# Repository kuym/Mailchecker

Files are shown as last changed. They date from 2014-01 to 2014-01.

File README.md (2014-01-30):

MailChecker2
============

This Electric Imp-powered device detects motion and reports it to you over the web.  It was originally designed to be stuck to a mailbox door
to notify you over WiFi when mail is delivered.  It could also be used to monitor doors (including garage or pet doors), valuables that you
don't want moved or cookie jars you want to keep children out of.

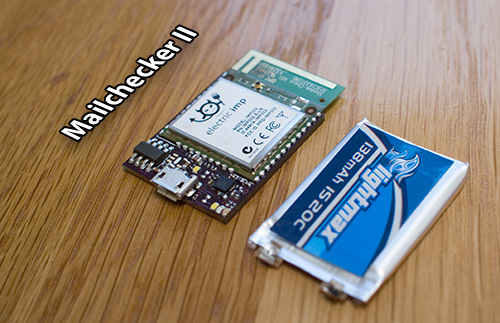
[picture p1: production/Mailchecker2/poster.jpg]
Poster


## Features

The board features an accelerometer, light sensor and Lithium-ion/polymer battery recharging built in.  It achieves approximately one month
of use between charges per 100mAh of battery capacity, assuming two motion activations per day.

This is a totally valid design but I intend to publish a newer version with Li-ion battery protection for unregulated cells.  The battery
attach terminals on the bottom are designed for a [138mAh Li-ion cell from HobbyKing](http://hobbyking.com/hobbyking/store/__37575__ZIPPY_138mAh_20C_Single_Cell_USA_Warehouse_.html),
which is an unregulated cell (and therefore can be fatally over-discharged by this design.)

## Board

[Order one from OSHPark](http://oshpark.com/shared_projects/IBBSjENY).

Submit the EAGLE sources or [gerber zip (Mailchecker2.zip)](../master/production/Mailchecker2) to your PCB fabricator to order your own.

## Parts

Check the [Bill of Materials](../master/production/Mailchecker2/Mailchecker2-parts.txt) to see what you already have that's an exact or close fit.
R1, R4 and R6 have important values.  All other resistors may be increased to 2x or decreased to 0.5x their specified value.
All capacitors may be increased of 2x their specified value.

## Assembly

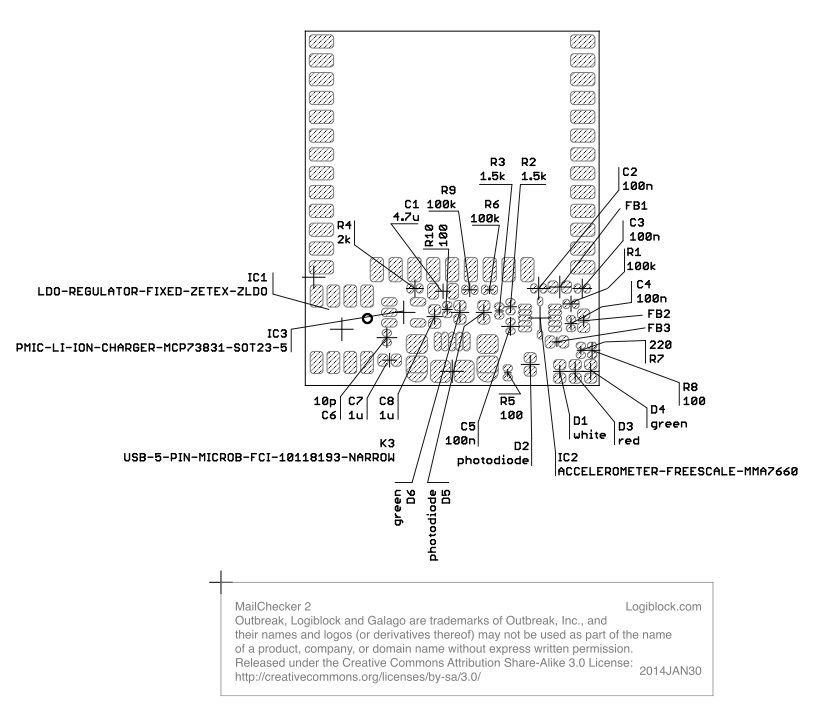
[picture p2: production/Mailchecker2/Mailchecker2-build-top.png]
Build diagram


## Firmware

Blink up the Imp and paste the squirrel source code in the [Electric Imp IDE](http://ide.electricimp.com).

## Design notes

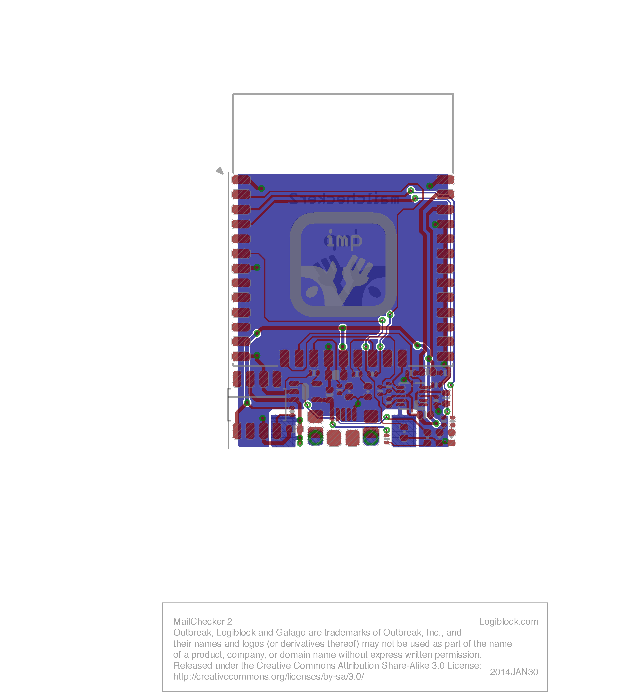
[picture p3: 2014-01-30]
production/Mailchecker2/Mailchecker2-board.png

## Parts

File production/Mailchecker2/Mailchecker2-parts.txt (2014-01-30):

Partlist

Exported from Mailchecker2.sch at 2014Jan30 12:10

EAGLE Version 6.1.0 Copyright (c) 1988-2012 CadSoft

Assembly variant: 

Part     Value                                Device                               Package                        Library  Sheet

C1       4.7u                                 CAP-0805-MIN                         0805-MIN                       Outbreak 1
C2       100n                                 CAP-0402-MIN                         0402-MIN                       Outbreak 1
C3       100n                                 CAP-0402-MIN                         0402-MIN                       Outbreak 1
C4       100n                                 CAP-0402-MIN                         0402-MIN                       Outbreak 1
C5       100n                                 CAP-0402-MIN                         0402-MIN                       Outbreak 1
C6       10p                                  CAP-0402-MIN                         0402-MIN                       Outbreak 1
C7       1u                                   CAP-0603-MIN                         0603-MIN                       Outbreak 1
C8       1u                                   CAP-0603-MIN                         0603-MIN                       Outbreak 1
D1       white                                LED-0603-MIN                         0603-DIODE-MIN                 Outbreak 1
D2       photodiode                           LED-0603-MIN                         0603-DIODE-MIN                 Outbreak 1
D3       red                                  LED-0603-MIN                         0603-DIODE-MIN                 Outbreak 1
D4       green                                LED-0603-MIN                         0603-DIODE-MIN                 Outbreak 1
D5       photodiode                           LED-0603-MIN                         0603-DIODE-MIN                 Outbreak 1
D6       green                                LED-0603-MIN                         0603-DIODE-MIN                 Outbreak 1
FB1                                           FERRITE-BEAD-0603-MIN                0603-MIN                       Outbreak 1
FB2                                           FERRITE-BEAD-0603-MIN                0603-MIN                       Outbreak 1
FB3                                           FERRITE-BEAD-0603-MIN                0603-MIN                       Outbreak 1
IC1      LDO-REGULATOR-FIXED-ZETEX-ZLDO       LDO-REGULATOR-FIXED-ZETEX-ZLDO       SM8-ZETEX                      Outbreak 1
IC2      ACCELEROMETER-FREESCALE-MMA7660      ACCELEROMETER-FREESCALE-MMA7660      QFN10-3X3MM-FREESCALE-MMA7660  Outbreak 1
IC3      PMIC-LI-ION-CHARGER-MCP73831-SOT23-5 PMIC-LI-ION-CHARGER-MCP73831-SOT23-5 SOT23-5                        Outbreak 1
K3       USB-5-PIN-MICROB-FCI-10118193-NARROW USB-5-PIN-MICROB-FCI-10118193-NARROW USB-MICROB-FCI-10118193-NARROW Outbreak 1
M1       WIFI-MODULE-ELECTRIC-IMP-002-MIN     WIFI-MODULE-ELECTRIC-IMP-002-MIN     ELECTRIC-IMP-002-MIN           Outbreak 1
R1       100k                                 RESISTOR-0402-MIN                    0402-MIN                       Outbreak 1
R2       1.5k                                 RESISTOR-0402-MIN                    0402-MIN                       Outbreak 1
R3       1.5k                                 RESISTOR-0402-MIN                    0402-MIN                       Outbreak 1
R4       2k                                   RESISTOR-0402-MIN                    0402-MIN                       Outbreak 1
R5       100                                  RESISTOR-0402-MIN                    0402-MIN                       Outbreak 1
R6       100k                                 RESISTOR-0402-MIN                    0402-MIN                       Outbreak 1
R7       220                                  RESISTOR-0402-MIN                    0402-MIN                       Outbreak 1
R8       100                                  RESISTOR-0402-MIN                    0402-MIN                       Outbreak 1
R9       100k                                 RESISTOR-0402-MIN                    0402-MIN                       Outbreak 1
R10      100                                  RESISTOR-0402-MIN                    0402-MIN                       Outbreak 1

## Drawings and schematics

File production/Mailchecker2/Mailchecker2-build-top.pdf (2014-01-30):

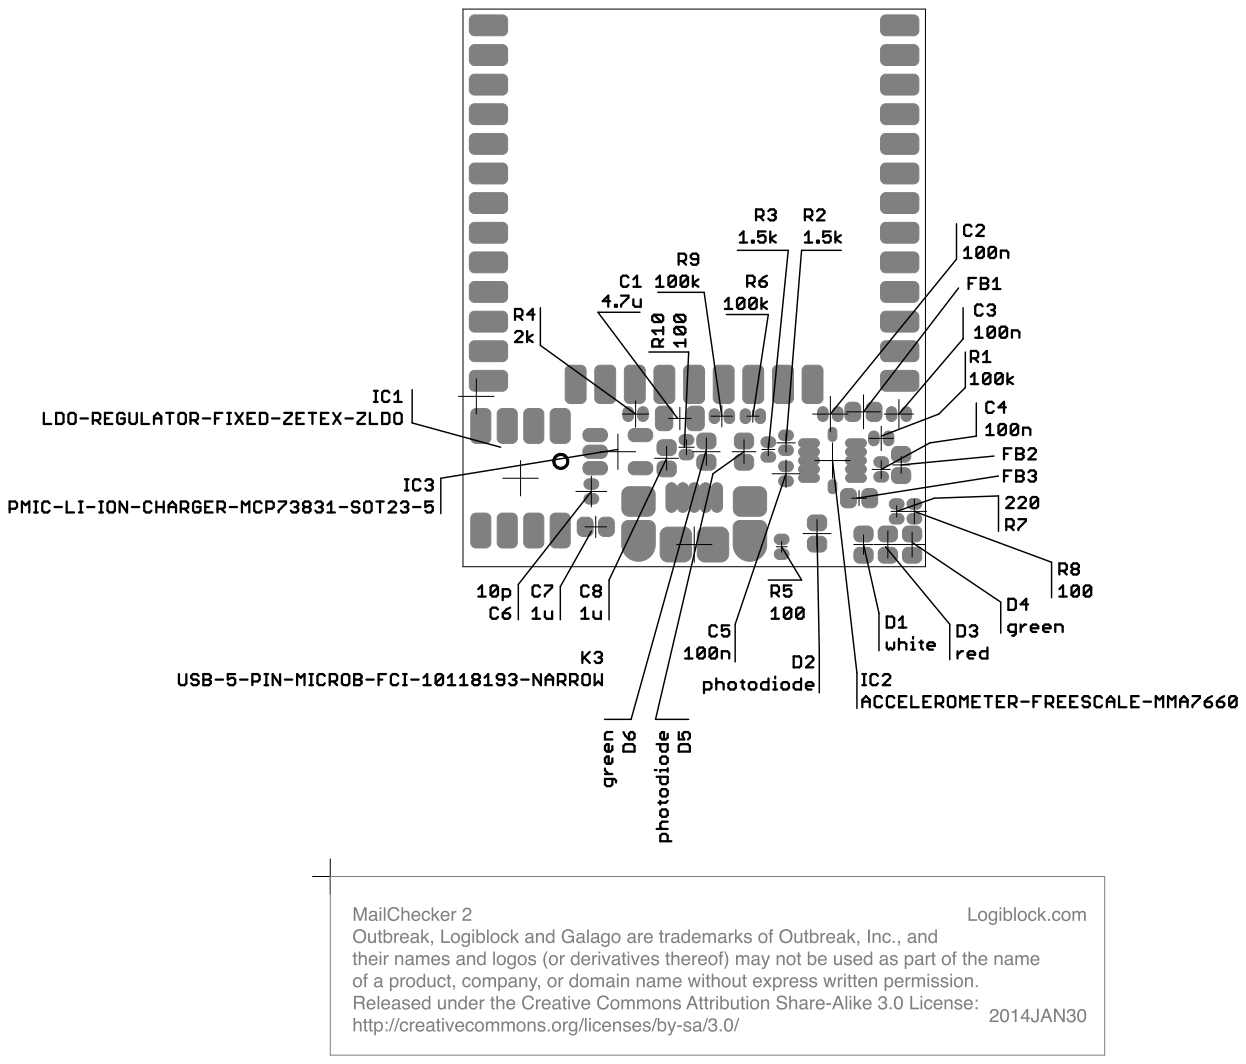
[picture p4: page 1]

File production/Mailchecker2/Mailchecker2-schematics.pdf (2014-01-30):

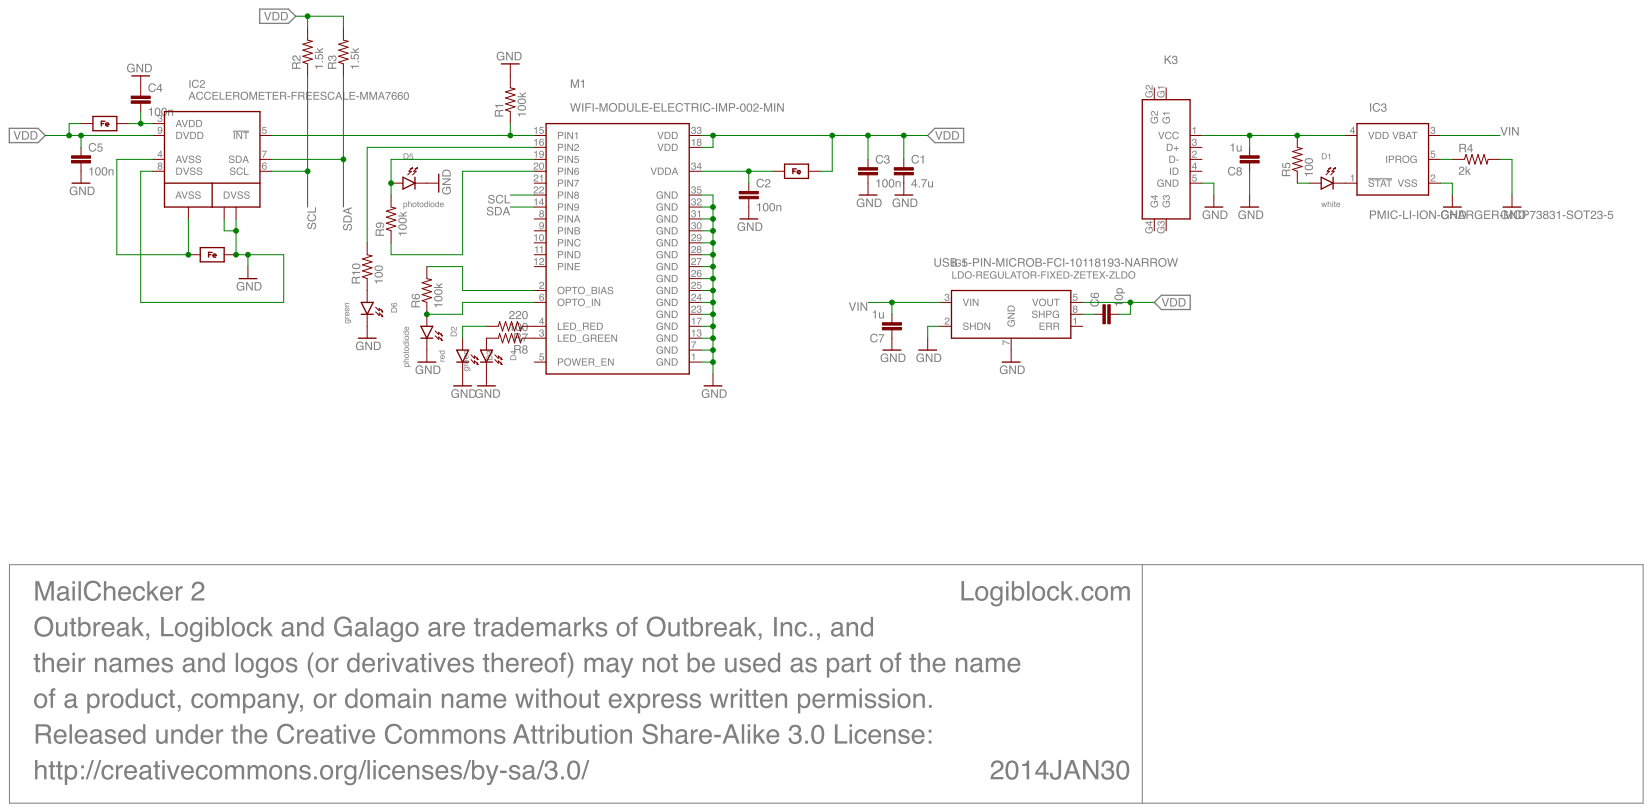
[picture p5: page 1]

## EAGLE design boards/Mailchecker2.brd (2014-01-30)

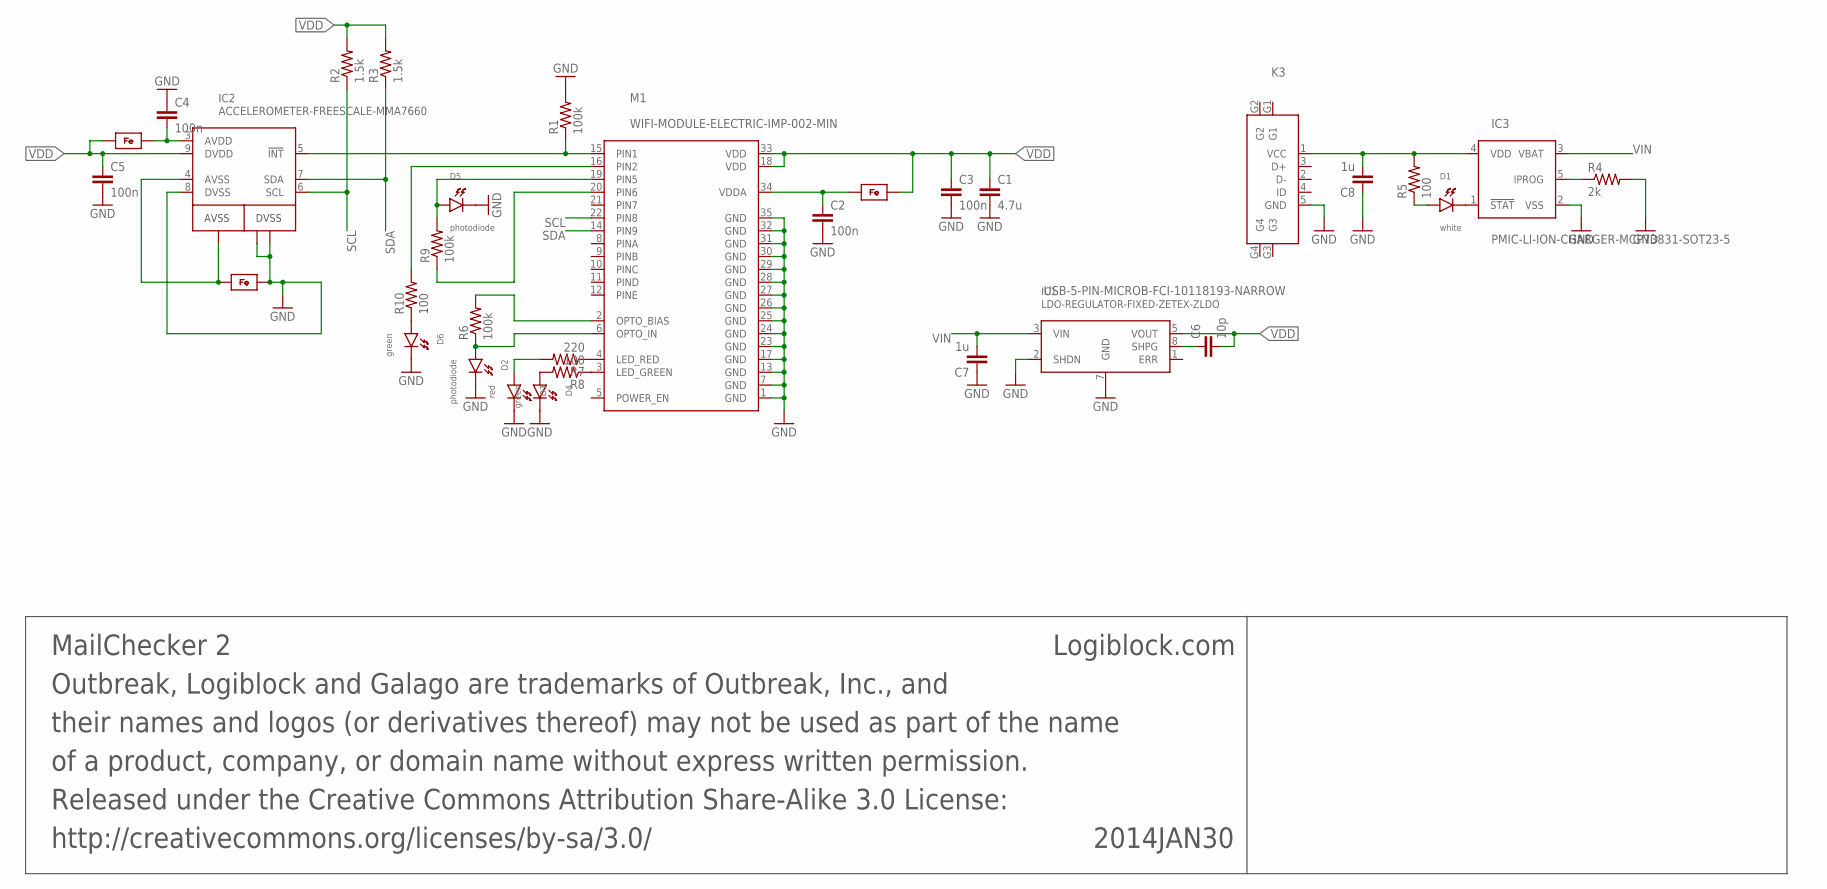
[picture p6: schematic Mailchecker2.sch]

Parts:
2014JAN30: MailChecker 2; INFO-BLOCK
C1: 4.7u; 0805-MIN
C2, C3, C4, C5: 100n; 0402-MIN
C6: 10p; 0402-MIN
C7, C8: 1u; 0603-MIN
D1: white; 0603-DIODE-MIN
D2, D5: photodiode; 0603-DIODE-MIN
D3: red; 0603-DIODE-MIN
D4, D6: green; 0603-DIODE-MIN
FB1, FB2, FB3: FERRITE-BEAD-0603-MIN; 0603-MIN
IC1: LDO-REGULATOR-FIXED-ZETEX-ZLDO; SM8-ZETEX
IC2: ACCELEROMETER-FREESCALE-MMA7660; QFN10-3X3MM-FREESCALE-MMA7660
IC3: PMIC-LI-ION-CHARGER-MCP73831-SOT23-5; SOT23-5
K3: USB-5-PIN-MICROB-FCI-10118193-NARROW; USB-MICROB-FCI-10118193-NARROW
M1: WIFI-MODULE-ELECTRIC-IMP-002-MIN; ELECTRIC-IMP-002-MIN
R1, R6, R9: 100k; 0402-MIN
R2, R3: 1.5k; 0402-MIN
R4: 2k; 0402-MIN
R5, R8, R10: 100; 0402-MIN
R7: 220; 0402-MIN

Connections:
AVDD: C4.1, FB3.2, IC2.3 (AVDD)
AVSS: FB2.1, IC2.1 (G3), IC2.4 (AVSS)
GND: C1.1, C2.1, C3.1, C4.2, C5.1, C7.2, C8.2, D2.K, D3.K, D4.K, D5.K, D6.K, FB2.2, IC1.2 (SHDN), IC1.7 (GND), IC2.8 (DVSS), IC2.G1, IC2.G2, IC3.2 (VSS), K3.5 (GND), M1.1 (GND), M1.7 (GND), M1.13 (GND), M1.17 (GND), M1.23 (GND), M1.24 (GND), M1.25 (GND), M1.26 (GND), M1.27 (GND), M1.28 (GND), M1.29 (GND), M1.30 (GND), M1.31 (GND), M1.32 (GND), M1.35 (GND), R1.2, R4.2
INT: IC2.5 (!INT), M1.15 (PIN1), R1.1
IPROG: IC3.5 (IPROG), R4.1
unnamed: M1.2 (OPTO_BIAS), R6.2
unnamed: M1.20 (PIN6), R9.1
unnamed: D1.K, IC3.1 (!STAT)
unnamed: D1.A, R5.1
unnamed: D2.A, M1.6 (OPTO_IN), R6.1
unnamed: M1.4 (LED_RED), R7.1
unnamed: M1.3 (LED_GREEN), R8.1
unnamed: D4.A, R8.2
unnamed: D3.A, R7.2
unnamed: D5.A, M1.19 (PIN5), R9.2
unnamed: M1.16 (PIN2), R10.2
unnamed: D6.A, R10.1
SCL: IC2.6 (SCL), M1.22 (PIN8), R2.1
SDA: IC2.7 (SDA), M1.14 (PIN9), R3.1
SHAPING: C6.2, IC1.8 (SHPG)
VCHARGE: C8.1, IC3.4 (VDD), K3.1 (VCC), R5.2
VDD: C1.2, C3.2, C5.2, C6.1, FB1.2, FB3.1, IC1.5 (VOUT), IC2.9 (DVDD), M1.18 (VDD), M1.33 (VDD), R2.2, R3.2
VDDA: C2.2, FB1.1, M1.34 (VDDA)
VIN: C7.1, IC1.3 (VIN), IC3.3 (VBAT)

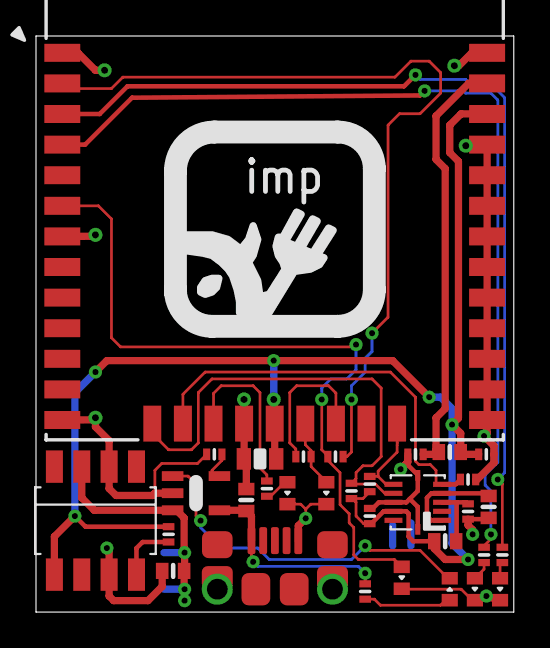
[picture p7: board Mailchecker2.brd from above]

Board: 2 copper layers, 26.5 x 32.0 mm, 33 parts (0 on the bottom side), 24 nets.

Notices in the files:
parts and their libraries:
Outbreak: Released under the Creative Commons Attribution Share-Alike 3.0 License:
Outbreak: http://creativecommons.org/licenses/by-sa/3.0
